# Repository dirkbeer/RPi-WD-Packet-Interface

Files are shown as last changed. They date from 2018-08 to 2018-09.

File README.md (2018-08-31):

Note: Schematic and board modified by dirkbeer to use an RJ-45 instead of a DB-9 connector. The RJ-45 pinout used is for the microphone connector on Baofeng mobile radios (e.g. UV-50x2). The text below is jaymzx's original readme.

# RPi-WD-Packet-Interface - A digital mode soundcard interface for the Raspberry Pi!

I set up an APRS igate using a Raspberry Pi device and a TNC-Pi 'hat'. While troubleshooting some other issues, I inadvertantly damaged the TNC-Pi, so I decided to go with a software TNC application. In this case, I chose [Dire Wolf](https://github.com/wb2osz/direwolf) by WB2OSZ. In his documentation, he specified a simple radio PTT interface that included a 'watchdog timer' to prevent a software issue from locking the radio into transmit. Working with WB2OSZ, I expanded the circuit and created a board with the following features:

### Selectable transmit and receive channels
* I noticed between sound card dongles, the mic input could be on the left or the right channel, depending on how much care the manufacturer put into it. A jumper lets you pick the channel that works with your card. I added a transmit channel selector for the same reason, but also so you can use a 'Y' cable with your stereo sound card and use two interfaces to work with two radios without any cable hacking.

### Transmit audio level pot
* The radio is expecting millivolts of input into its MIC input. Modern sound cards can put out more than 2V peak to peak. This is really bad for distortion and over-deviation. Right now, I use about 40% volume on the sound card, and 20% volume on the pot. The audio is DC isolated with a capacitor to prevent phantom voltage (for electret microphones) from either the sound card or the radio from damaging anything.

### Adjustable watchdog delay
* Most people will use this for packet, but some others may use it for things like RTTY, JT-65, QRSS or any other digital mode that has a long duty cycle. I added a big cap and 25-turn trimmer for a delay adjustable between 0 and 110 seconds with the parts specified. One can solder in a fixed resistor or change values for something that doesn't need to be adjusted. [Calculators](http://www.ohmslawcalculator.com/555-monostable-calculator) are out there.

### DCD (received packet) LED
* The newest version of Dire Wolf can trigger a GPIO pin to signal a successfully decoded packet. Just bring this pin 'high' and the yellow DCD LED will light up. Yay. Good for watching activity at-a-glance from across the shack.

### Selectable single-wire handheld PTT or 'Kenwood' dedicated PTT wire method
* Most HTs use a resistor to ground on the microphone input to trigger PTT. Kenwood/Baofeng and some others have to be different and ground the mic shield to trigger. You can set a jumper to select whatever method you need.
	
### Standard Kantronics DB-9 radio interface
* I already had some cables I made and bought for radios when using my KPC3. The TNC-Pi and (I believe) the TinyTrak and OpenTracker devices use the same standard. This makes it easy to buy cables if you don't want to make them, or re-use ones you already have kicking around. FWIW, I hate DB9 connectors and prefer RJ-45 for these purposes, but I wanted to make it 'standard'. Signalink and RigBlaster use a similar (although RB is reversed) RJ-45 standard, but it's not as prolific. In case someone hates DB-9 as much as I do, I called out the signals on the pads to which they can be directly soldered for a cable, header pins, etc.

### Native 3.3v Rpi logic levels
* Using this board as configured works with the 3.3v logic the RPi uses. If you use another controller (like an Arduino) you *can* use 5V logic as the LMC555 CMOS can handle it without a sweat, but you will need to change the resistor values for the LEDs and transistor bias. You can also skip 3.3v altogether if you want to use it with a 5V microcontroller and use a cheap and widely-available LM555N (and the appropriate resistor changes).

### Uses standard 60mm x 60mm 'Sick of Beige' PCB size
* Just like the [xkcd](https://xkcd.com/927/) comic about standards, there is a new PCB size standard for the Maker crowd called [Sick of Beige](http://dangerousprototypes.com/docs/Sick_of_Beige). They have some cool acrylic cases at [Seeed Studios](http://www.seeedstudio.com/depot/Sick-Of-Beige-Basic-Case-v1-60mm-Square-DP6060-p-1329.html), but you can probably find others or fab up your own. The original board was smaller, but in order to fit into the SoB standard size, the minimum size that would fit the DB-9 connector is 60mm. Please note this is *not* a 'hat' for the RPi. It's a separate board. 

### Open Hardware
* I put the time into it, but like most of my projects, once it's done, it's done. I figure others can benefit from my work, so I may as well pass it on. This project is licensed under [Creative Commons Attribution-ShareAlike](https://creativecommons.org/licenses/by-sa/3.0/), so you can edit it, improve it, remix it into another project, make and sell PCBs or kits, etc. You just need to specify a link back to the original source (here) to comply. It's no big deal.
		
### Readily-available parts
* You probably have most of these parts in your bin, but things like the 3.5mm and DB-9 connectors are available at [SparkFun](https://www.sparkfun.com/). I specified genuine Borne trimpots in the PCB footprints but they are commonly used by others. You can find them at [Mouser](http://www.mouser.com/) or many other places.

You can order a [pre-made PCB from OSH Park](https://oshpark.com/shared_projects/dotsia3r) (with the beautiful purple solder mask as shown). They come in multiples of three, so order some for your friends or make a couple for a multi-rig interface. You can also take the Eagle files and have them made elsewhere, or make your own using a toner transfer or photo etch PCB process. Go nuts.

# Known issues
None at this time. 

# Improvements
I'm kicking around the idea of an RJ-45 version of this board, which would be a simple redesign. I also have on the drawing board an isolated version with transformers and opto-isolated PTT control. I welcome discussion around this, and if you can't wait, feel free to fork this project!

## Enjoy the interface, and see you on the air.

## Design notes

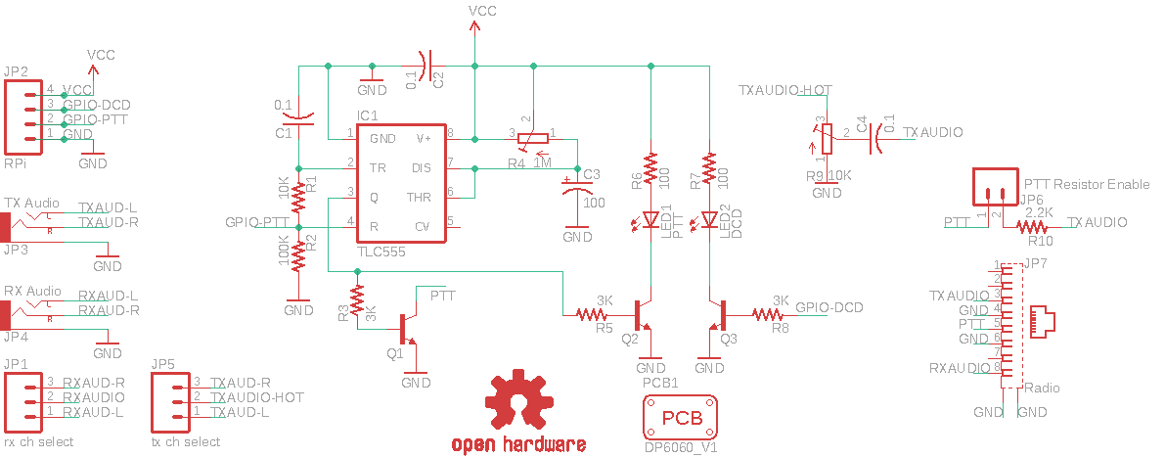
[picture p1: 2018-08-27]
Schematic v1.0.png

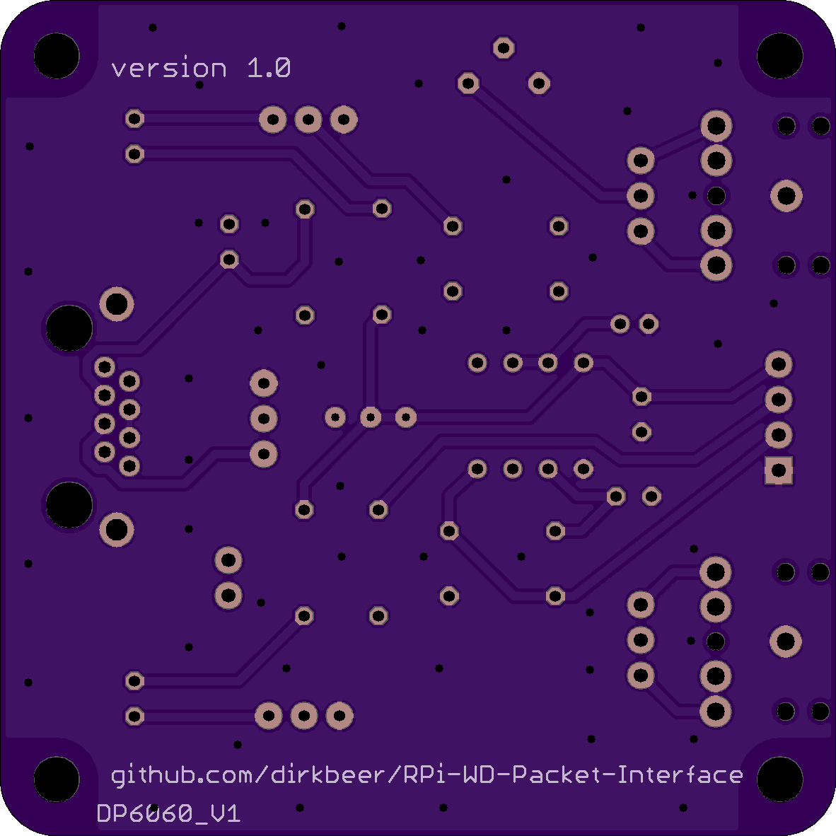
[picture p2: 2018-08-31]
RPi WD Packet Interface RJ45 Layout v1.0 - Render - Bottom.png

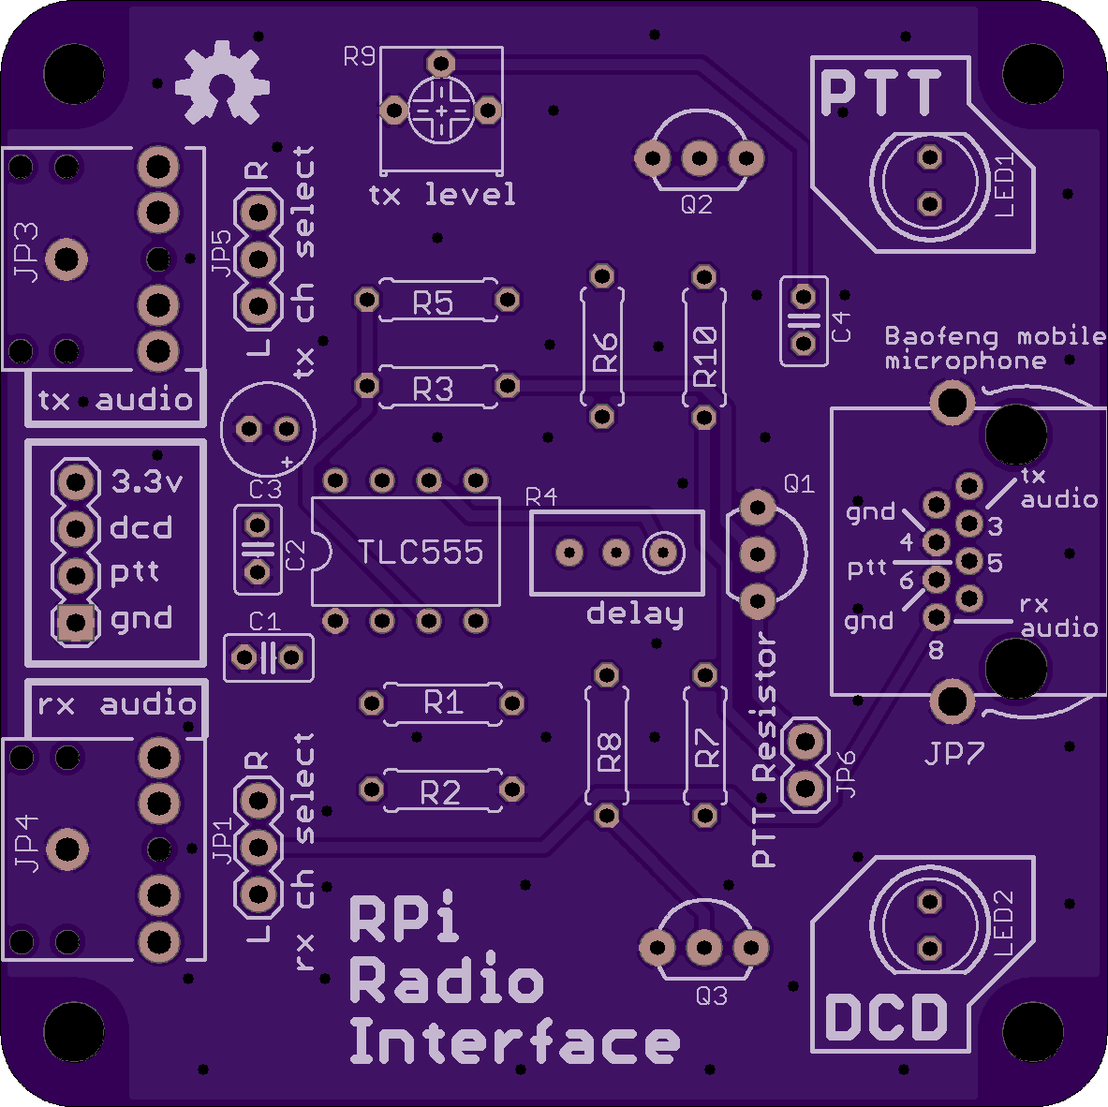
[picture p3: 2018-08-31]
RPi WD Packet Interface RJ45 Layout v1.0 - Render - Top.png

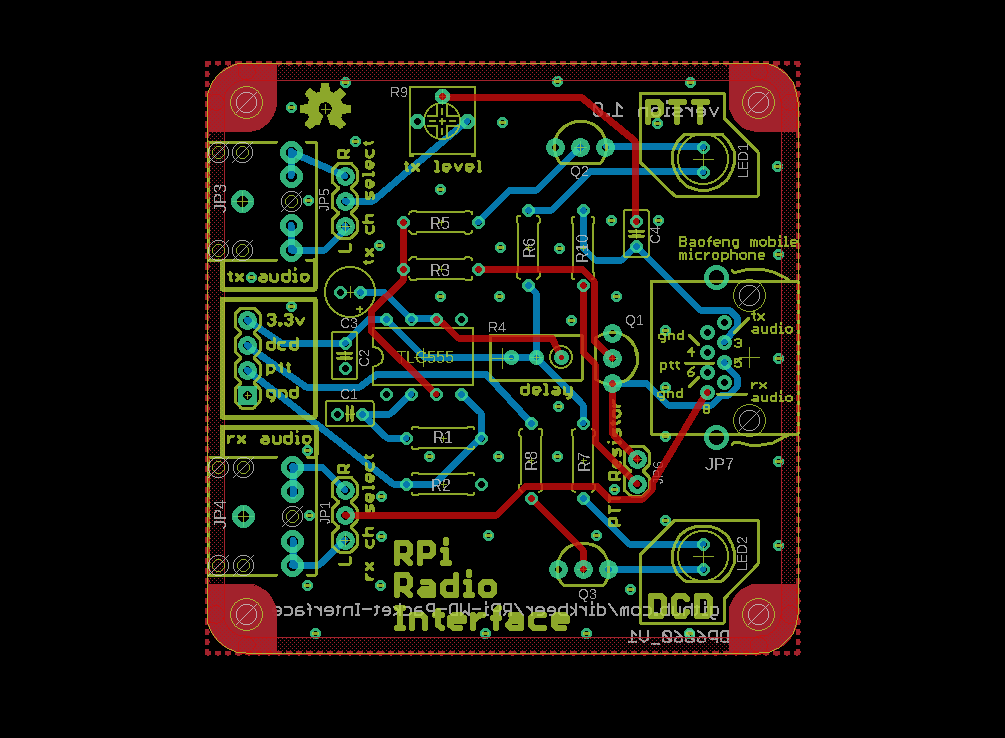
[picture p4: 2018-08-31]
RPi WD Packet Interface RJ45 Layout v1.0.png

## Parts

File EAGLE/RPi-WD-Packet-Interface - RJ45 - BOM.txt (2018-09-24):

Partlist exported from /home/familybeer/RPi-WD-Packet-Interface/EAGLE/RPi-WD-Packet-Interface - RJ45.sch at 8/26/18 9:48 PM

Part  Value               Device                   Package      Description                                                     MF    MPN        OC_FARNELL PCB_SIZE 
C1    0.1                 C-US025-025X050          C025-025X050 CAPACITOR, American symbol                                                                           
C2    0.1                 C-US025-025X050          C025-025X050 CAPACITOR, American symbol                                                                           
C3    100                 CPOL-USE2-5              E2-5         POLARIZED CAPACITOR, American symbol                                                                 
C4    0.1                 C-US025-025X050          C025-025X050 CAPACITOR, American symbol                                                                           
IC1   TLC555              TLC555                   DIL08        TIMER                                                                                                
JP1   rx ch select        M03PTH                   1X03         Header 3                                                                                             
JP2   RPi                 M04PTH                   1X04         Header 4                                                                                             
JP3   TX Audio            AUDIO-JACKPTH            AUDIO-JACK   3.5mm Audio Jack                                                                                     
JP4   RX Audio            AUDIO-JACKPTH            AUDIO-JACK   3.5mm Audio Jack                                                                                     
JP5   tx ch select        M03PTH                   1X03         Header 3                                                                                             
JP6   PTT Resistor Enable M02PTH                   1X02         Standard 2-pin 0.1" header. Use with                                                                 
JP7   Radio               0446200002               0446200002   RJ-45 INVERTED MODULAR JACK ASSEMBLY WITH RJ-11 KEEPOUT FEATURE MOLEX 0446200002 9251910             
LED1  PTT                 LED5MM                   LED5MM       LED                                                                                                  
LED2  DCD                 LED5MM                   LED5MM       LED                                                                                                  
LOGO1 OSHW-LOGOM          OSHW-LOGOM               OSHW-LOGO-M  Open Source Hardware Logo                                                                            
PCB1  PCB_DP_SQUARE-6X6   PCB_DP_SQUARE-6X6        DP6060_V1    Dangerous Prototypes Standard Square PCB sizes                                              DP6060_V1
Q1    PTT                 TRANSISTOR_NPNTO-92-AMMO TO-92-AMMO   Generic NPN BJT                                                                                      
Q2    PTT-LED             TRANSISTOR_NPNTO-92-AMMO TO-92-AMMO   Generic NPN BJT                                                                                      
Q3    DCD-LED             TRANSISTOR_NPNTO-92-AMMO TO-92-AMMO   Generic NPN BJT                                                                                      
R1    10K                 R-US_0207/7              0207/7       RESISTOR, American symbol                                                                            
R2    100K                R-US_0207/7              0207/7       RESISTOR, American symbol                                                                            
R3    3K                  R-US_0207/7              0207/7       RESISTOR, American symbol                                                                            
R4    1M                  R-TRIMM3296W             RTRIM3296W   Trimm resistor                                                                                       
R5    3K                  R-US_0207/7              0207/7       RESISTOR, American symbol                                                                            
R6    100                 R-US_0207/7              0207/7       RESISTOR, American symbol                                                                            
R7    100                 R-US_0207/7              0207/7       RESISTOR, American symbol                                                                            
R8    3K                  R-US_0207/7              0207/7       RESISTOR, American symbol                                                                            
R9    10K                 RTRIM-3362P              RTRIM3362P   BOURNS 3362 - 1/4" Square Trimpot® Trimming Potentiometer                                            
R10   2.2K                R-US_0207/7              0207/7       RESISTOR, American symbol

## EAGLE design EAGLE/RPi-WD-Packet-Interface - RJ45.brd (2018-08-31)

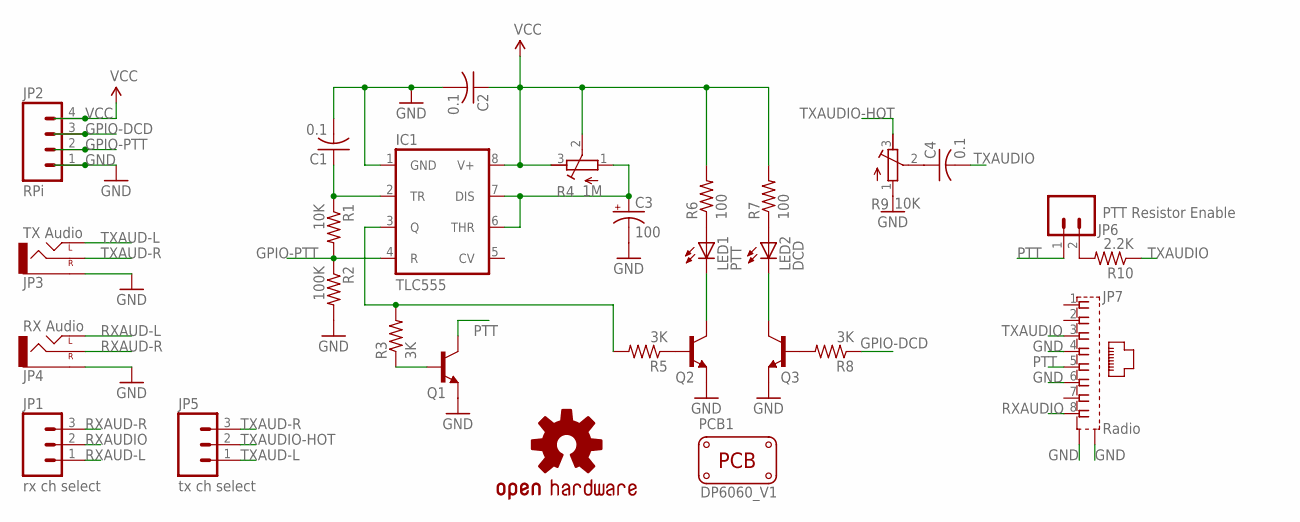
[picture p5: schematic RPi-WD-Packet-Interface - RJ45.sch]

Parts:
C1, C2, C4: 0.1; C025-025X050
C3: 100; E2-5
IC1: TLC555; DIL08
JP1: rx ch select; 1X03
JP2: RPi; 1X04
JP3: TX Audio; AUDIO-JACK
JP4: RX Audio; AUDIO-JACK
JP5: tx ch select; 1X03
JP6: PTT Resistor Enable; 1X02
JP7: Radio; 0446200002
LED1: PTT; LED5MM
LED2: DCD; LED5MM
LOGO1: OSHW-LOGOM; OSHW-LOGO-M
PCB1: PCB_DP_SQUARE-6X6; DP6060_V1
Q1: PTT; TO-92-AMMO
Q2: PTT-LED; TO-92-AMMO
Q3: DCD-LED; TO-92-AMMO
R1: 10K; 0207/7
R2: 100K; 0207/7
R3, R5, R8: 3K; 0207/7
R4: 1M; RTRIM3296W
R6, R7: 100; 0207/7
R9: 10K; RTRIM3362P
R10: 2.2K; 0207/7

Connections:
GND: C1.2, C2.2, C3.-, IC1.1 (GND), JP2.1, JP3.SLEEVE, JP4.SLEEVE, JP7.4, JP7.6, JP7.S@1 (S1), JP7.S@2 (S2), Q1.1 (E), Q2.1 (E), Q3.1 (E), R2.2, R9.1
GPIO-DCD: JP2.3, R8.1
GPIO-PTT: IC1.4 (R), JP2.2, R1.2, R2.1
unnamed: LED1.A, R6.1
unnamed: LED2.A, R7.1
unnamed: C1.1, IC1.2 (TR), R1.1
unnamed: C4.1, R9.2
unnamed: C3.+, IC1.6 (THR), IC1.7 (DIS), R4.1 (A)
unnamed: LED1.K (C), Q2.3 (C)
unnamed: Q2.2 (B), R5.1
unnamed: Q1.2 (B), R3.1
unnamed: LED2.K (C), Q3.3 (C)
unnamed: Q3.2 (B), R8.2
unnamed: JP6.2, R10.2
PTT: JP6.1, JP7.5, Q1.3 (C)
PTT_TRIGGER: IC1.3 (Q), R3.2, R5.2
RXAUD-L: JP1.1, JP4.TIP (LEFT)
RXAUD-R: JP1.3, JP4.RING (RIGHT)
RXAUDIO: JP1.2, JP7.8
TXAUD-L: JP3.TIP (LEFT), JP5.1
TXAUD-R: JP3.RING (RIGHT), JP5.3
TXAUDIO: C4.2, JP7.3, R10.1
TXAUDIO-HOT: JP5.2, R9.3
VCC: C2.1, IC1.8 (V+), JP2.4, R4.2 (S), R4.3 (E), R6.2, R7.2

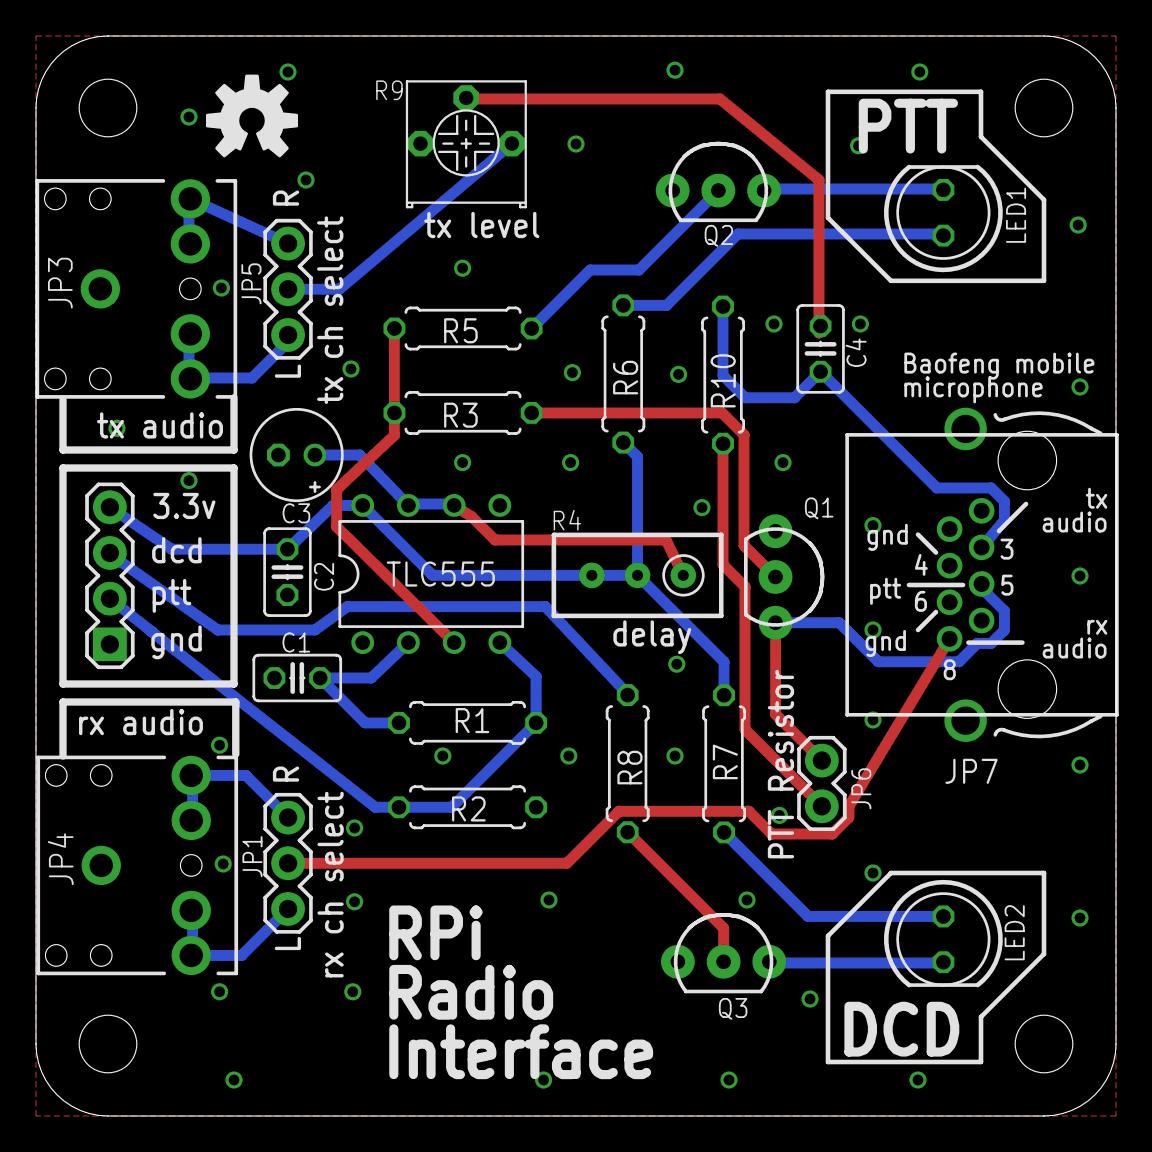
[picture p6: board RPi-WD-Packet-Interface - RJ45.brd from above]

Board: 2 copper layers, 60.0 x 60.0 mm, 29 parts (0 on the bottom side), 24 nets.

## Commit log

2018-08-27 Replace DB-9 files with RJ-45 version 1.0
    [RPi-WD-Packet-Interface - RJ45.brd, RPi-WD-Packet-Interface - RJ45.sch]
2018-08-27 Added RJ-45 Gerber files and made note in Readme
2018-08-27 Added RJ-45 Gerber files, second try
2018-08-27 Removing old BOM and trying to get README to update
2018-08-31 RJ-45 rotation fix & silkscreen update
    [RPi-WD-Packet-Interface - RJ45.brd]
2018-08-31 Updated renderings and board layout image.
2018-09-24 Update RPi-WD-Packet-Interface - RJ45 - BOM.txt
    specify CMOS 555

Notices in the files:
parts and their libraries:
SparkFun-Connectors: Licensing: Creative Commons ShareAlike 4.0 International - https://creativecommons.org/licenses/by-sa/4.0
